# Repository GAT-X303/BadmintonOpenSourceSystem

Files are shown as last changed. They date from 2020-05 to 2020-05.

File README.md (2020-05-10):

# BOSS - Badminton Open Source System

## Introduction
Badminton can be costly to play with the ever growing cost of equipment. However, it is also important to train fundamentals through drilling. This can be hard for people who lack skilled training partners and most resort to coaching. Coaching itself can be expensive and at time it can be more productive to work on other skills instead of basic shots. BOSS aims to fix this by providing an open source badminton feeding system that will help those who cannot afford it, or those who choose not to.

Please see a detailed overview on my website
https://gat-x303.github.io/projects/BOSS/BOSS.html

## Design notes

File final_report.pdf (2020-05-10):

# BADMINTON OPEN SOURCE SYSTEM

## Final Project Report

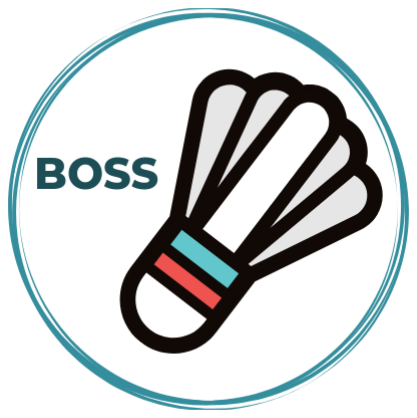
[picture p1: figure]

### APRIL 11, 2019

ENGINEERING DESIGN – ELECENG 4OI6 Nicholas Amoirm Dyllan Appelbohm Allan Hieng Mackenzie Wiens

## Table of Contents

### Acknowledgements

We would like to acknowledge Dr. Shirani for all his support, Gavin Crasto for his assistance 3D printing components, and the boys of 26 Haddon for letting us take over their living room during the build. Lastly, thank you to all women in the engineering, for without equal representation we will always fail in our duty to society.

## Final Report

### Introduction

The BOSS (Badminton Open Source System) is a badminton birdie launching system that reduces training obstacles for players of all socio-economic backgrounds. This system contains the physical launching device and a user-friendly android app that when paired together create a training environment for all! Within the app, user will have the option to select either pre-programmed launching patterns or create their own based on the type of shot, and the lateral location they wish to receive it.

Motivation
Badminton is a growing sport in Canada and is popular worldwide. A common limitation for players is the lack of consistent training scenarios. The BOSS System is an open source programmable Bluetooth device that will act as an accurate launcher. Ideally this device is an affordable option for players of all levels.

Background
In badminton training programs there are very few alternatives to private coaching. One alternative that some have tried to capitalize on are automatic feeding machines. However, these machines are not robust, difficult to purchase, and expensive. One of these machines is the patent-pending Black Knight Trainer Pro. This device has basic functionality and is not user-friendly. It requires the user to bring a laptop with a rudimentary desktop application. Furthermore, this device is not even available for purchase. The newest product is the Baddy, a badminton “robot” that you can assemble yourself or purchase ready-to-go. This device has a mobile application (although its interface is not intuitive) and does function, but it is very expensive. It cost approximately $600 CAD plus shipping (from Europe). Furthermore, this device is not open source, so any type of improvements would be very difficult to implement. Our objective was to build an open source, user-friendly, economic, automatic shuttlecock launcher. This will ultimately grow the game of badminton through providing better training opportunities to all athletes regardless of economic class.

There are six main types of badminton
shots (as seen in Figure 1), the BOSS in its
current iteration can hit three: smash (middle back of court), drop (middle of the court), net-drop (front of court) in 3 separation lateral directions (left, center, right) for a total of nine separate shots.

Project Goals & Planned Approach

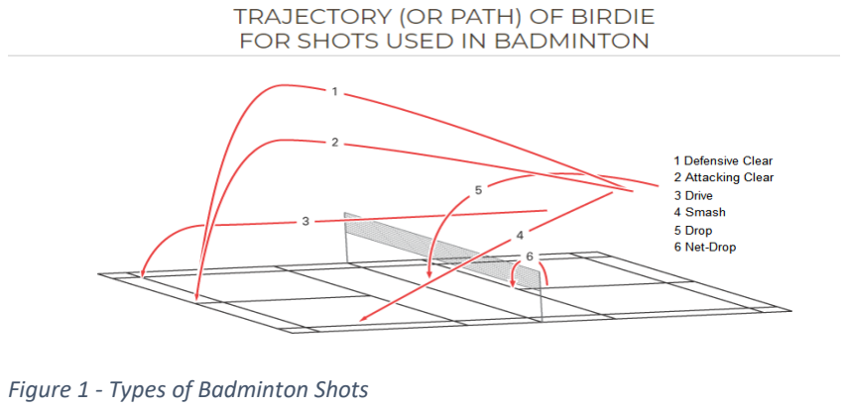
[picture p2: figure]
Figure 1 - Types of Badminton Shots

Our proposed Gold Project” had the following features:

Physical Device | Android App Capability
- Lateral movement (left, right, center)
- Linear movement (to hit back court
shots)
- Bluetooth connection
- Pre-programmed shot locations
- Ability to customize patterns for shots

- Battery Powered
- All STL files open source
- Open source app template
- Open source Arduino code The device that we created included the following features:
Physical Device | Android App Capability
- Lateral movement (left, right center)
- Piston to control back, middle, or front
shots
- Only Brushless Motors Battery Controlled
- All STL and SVG files open source
- Bluetooth connection
- Press shot location and device shoots
- Within the app: opportunity for pre-
| programmed shot locations and ability to customize patterns for shots. But not on the Arduino end.
- Open source app template
- Open source Arduino code
Milestone Descriptions | Start Date | End Date | H
M1: Build launching mechanism | October 2018 | December 2018 | 50
M2: Prototype wheels to reduce slip | October 2018 | March 2019 | 30
M3: connect Arduino to brushless and stepper motors | December 2018 | February 2019 | 40
M4: Android app development | January 2019 | March 2019 | 60
M5: Build launch tube and birdie ramp | March 2019 | March 2019 | 20
M6: Design and testing of piston | March 2019 | April 2019 | 20
M7: Assembly of physical device (laser cut gears, mounts, and housing) | March 2019 | April, 2019 | 10
M8: Integrate the physical design (launching stepper motors, direction stepper motors, and brushless motors) with Arduino | April, 2019 | April 7th, 2019 | 10
M9: Integrate android app with Arduino | April 7th, 2019 | April 8th, 2019 | 5
M10: Final testing and tweaking | April 8th, 2019 | April 8th, 2019 | 10

Table 1 - Timeline of Milestones & Hours Worked

### Approach Taken

Design

Basic Technical Approach
1. Develop and build a mechanism using two brushless motors to launch a shuttlecock by applying voltage to the motors.
2. Test different wheel materials and sizes for the best results
3. Introduce secondary stepper motors to move the original mechanism left and right (lateral movement).
4. Laser cut gears to increase torque and direction for the device when moving laterally.
5. Create the wood housing for the device.
6. Design a passive feed tube to hold birdies and use stepper motors to dispense.
7. Design sliding ramp (piston) system to alter shot distance.
8. Begin Arduino code development
a.
9. Integrate Arduino with device for controlling motor voltages.
10. Attach device to tripod; design and implement attachment.
11. Test and record ramp position based on required distance and lateral direction.
12. Android app development
a. Sketch app flow
b. Design background images
c. Create homepage
d. Create buttons that open a new activity (new page)
e. Create an array & variable to store the int that will be sent to the Arduino
f. Create Bluetooth protocol (open socket to connect with Arduino)
13. Integrate device with app
14. Integrate battery power into the device.
15. Fine tune the aim of device both longitudinally and laterally.

Design Process
The process of designing the device revolved around the goal to shoot one undamaged birdie at a time to consistent locations by controlling the vertical angle, horizontal angle, and power of the shot. Keeping simplicity in mind, a flywheel system was chosen as the best way to launch the birdies. Since the flywheels would damage the feathers significantly, the feeding system was designed to keep the feathers of the birdie upright so they wouldn’t get caught. During testing a track was implemented to easily feed the birdie into the wheels and due to pivoting flywheels pivot point was made around the center point of the birdie so that the track could remain stationary (as seen in the below figures). Lastly, two interlocking gears were used to turn the flywheels left and right so the stepper motors did not have to be powerful and to reduce the weight that would be directly resting on one motor.

At this point in the design process the ability to vary the vertical angle of the shot was abounded due to the difficulty it would take to pivot the entire machine. The BOSS was mounted at a constant angle of 12 degrees using a tripod to get the most distance out of the shots.

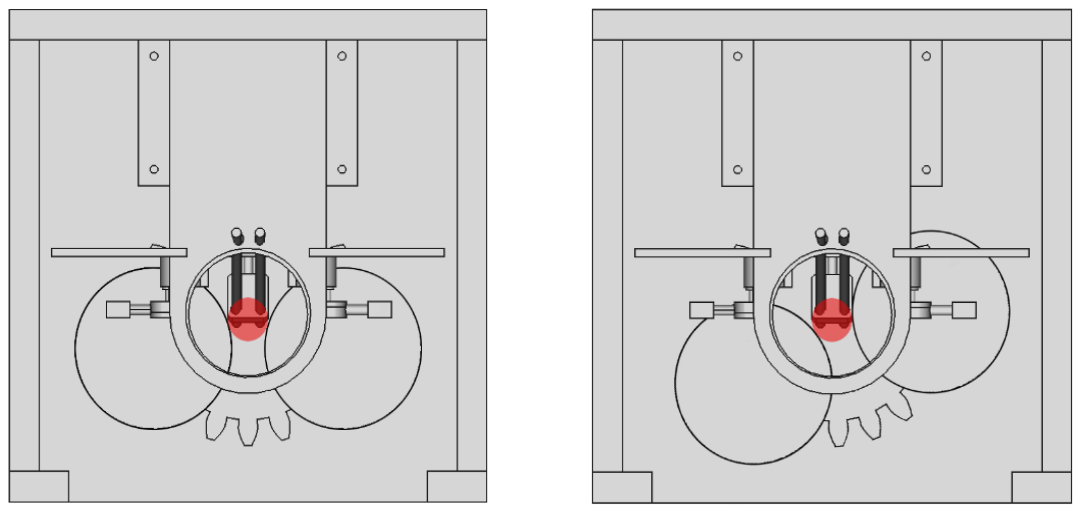
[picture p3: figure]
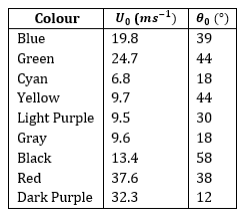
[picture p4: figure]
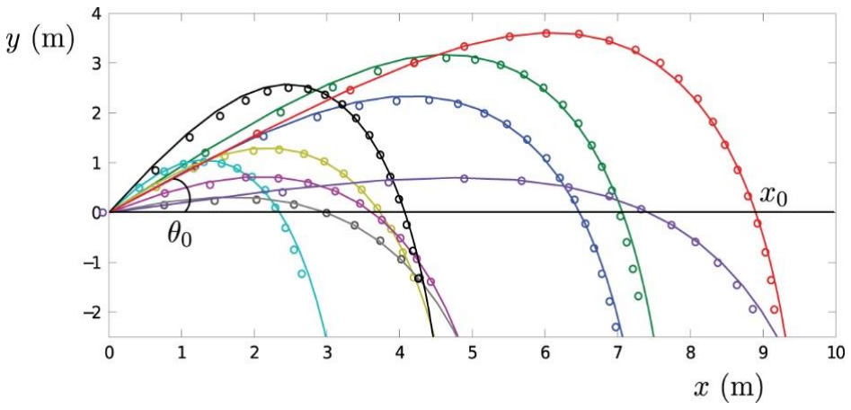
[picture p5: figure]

Figure 4 - Comparison between the observed trajectories (circles) and trajectories calculated with a pure drag equation and (solid line) for different initial conditions.

The next challenge was moving the birdie from the storage tube to the flywheels. A 3-inch mailing tube and the elastic part of a sock was used to hold back the birdies before changing the sock for a foam gasket. The supports for the tube and the dropper were designed to fit together nicely to add additional stability to the dropper arms. The arms were tipped with the same foam material
that the tube gasket was made from due to its soft and springy
properties.The last challenge was to come up with a way to vary the
distance that the birdie was shot. Varying the speed of the brushless motors did not change the distance of the shot significantly since the brushless motors were too weak to deal with the resistance of the birdie. A solution was found while manually feeding birdies through the flywheels, when the cork on the birdy didn’t line up properly with the wheels the birdie didn’t travel as far. A small piston was designed to adjust the distance between the track and the wheels
which would allow us to control how much of the cork would be
gripped by the flywheels. This allowed the BOSS to shoot net shots
as well as the farthest shots. | Table 2 - Initial Conditions for Figure 4

Figure 2 - The track remains stationary while the flywheels rotate around the center point of the

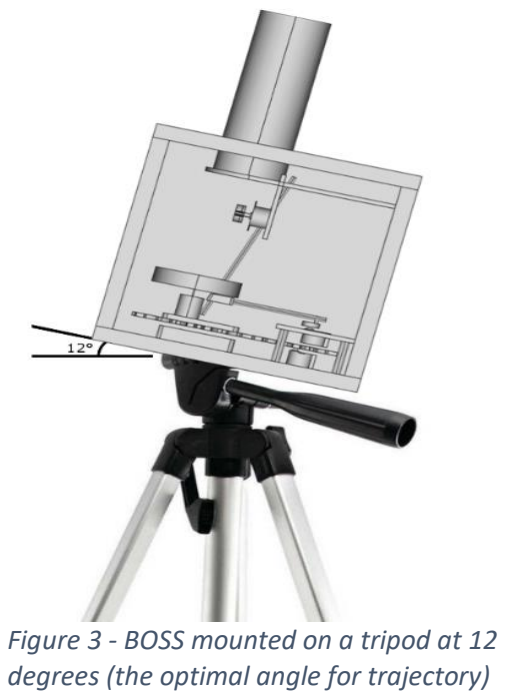
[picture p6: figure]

Figure 3 - BOSS mounted on a tripod at 12 degrees (the optimal angle for trajectory)

Modeling & Simulation
Device Drawing

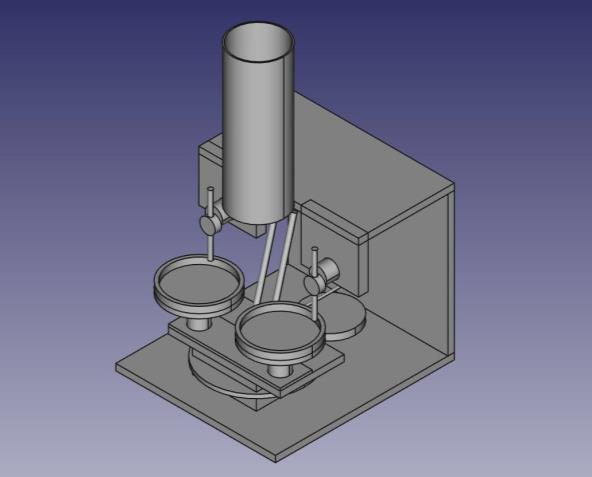
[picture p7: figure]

Laser Cut Parts
- Pulldown motor hub (2)
- Flywheels (2)
- Piston motor hub
- Feed ramp connector

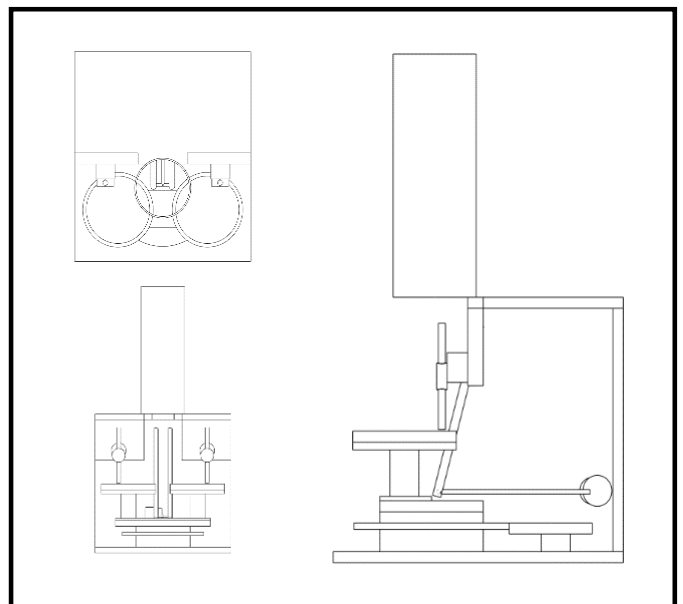
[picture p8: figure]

3D Printed Parts
- Main & Secondary gears
- Brushless motor plate
- Lazy Susan bearing spacer
- Piston motor shelf
- Tube mounting plate
- Pull down motor mounting plate

Implementation
Physical Device
The BOSS device contains five stepper motors controlled by an Arduino which is controlled via a Bluetooth connection from an Android App. Two stepper motors are used to pull one birdie at a time from the gravity tube feeder and load them onto the track. The track position (lateral direction) and launch (linear) distance is determined by two other stepper motors. One of the steppers turns a gear which controls the lateral direction and the other stepper motor is the piston mechanism. Brushless motors are moved using a servomotor connected to a The Arduino is connected to an electronic speed controller to spin two brushless motors which are connected to flywheels that launch the birdies. When the birdie slides down the track, it is launched when it contacts the rotating flywheels

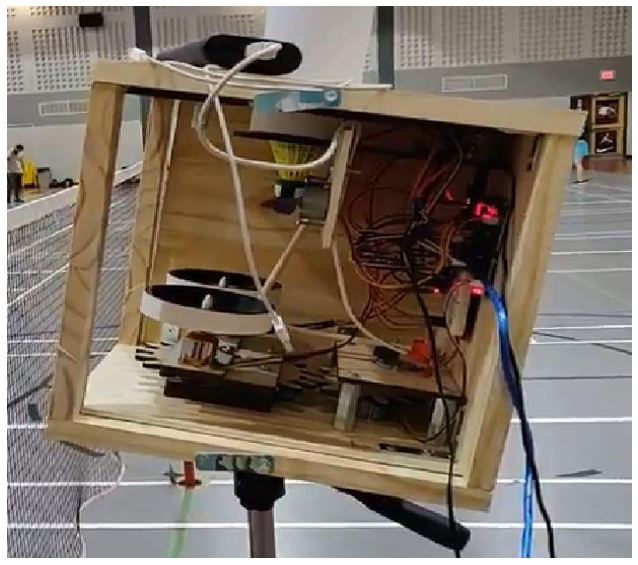
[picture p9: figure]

Figure 5 - BOSS Use Flowchart

Arduino
The Arduino is main controller of the entire device. It connects the Android app to the hardware using a Bluetooth module, the HC-06. It controls the 4 stepper motors, and the brushless motors. It provides power for the piston and bearing stepper motors. It does not provide power for the feeder stepper motors as they require more amperage to do their job. It provides the brushless motors with a square wave that is generated through pin 3, which controls the speed of the brushless motors. The AccelStepper and MultiStepper libraries were used, since they abstracted some controls of the stepper motors. These libraries were to used to control the speed and position of the various components.

The Arduino accepts Bluetooth inputs with a baud rate of 9600 since speed is not a constraint and very little data is sent at once. Once it receives data from the HC-06, a protocol designed is used to control the next actions. An integer is received, and a case statements determines the actions based on Table 5. it is ALWAYS required to press reset before powering off the device. Because it moves the device to the 0 position and all the other positions are based of this location being 0.To move each stepper motor, a function stepper.moveTo(num) was used. Where num is an integer value relative to its start position which is 0. Moving clockwise requires a positive integer, while the opposite is true for a negative number. Since the steppers used are 8 steps, the following values are used to move to key positions. Except for the feeder motors, the other motors used some values in between the key values.

The brushless motors are powered separately as they take a burst of current to run, which the Arduino cannot handle. However, the speed can be controlled by the Arduino. Since they are controlled by the duty cycle % of the PWM. Using analogWrite(pwm_pin, duty_cycle), the % duty cycle can be controlled. Anything above 60% turns the motors on. For 100% duty cycle, the value of 255 is used with 0 being 0%. 149(58%) was used for off, while 160(63%) was used was as on. These values were found by testing as the PWM of the Arduino had some noise.

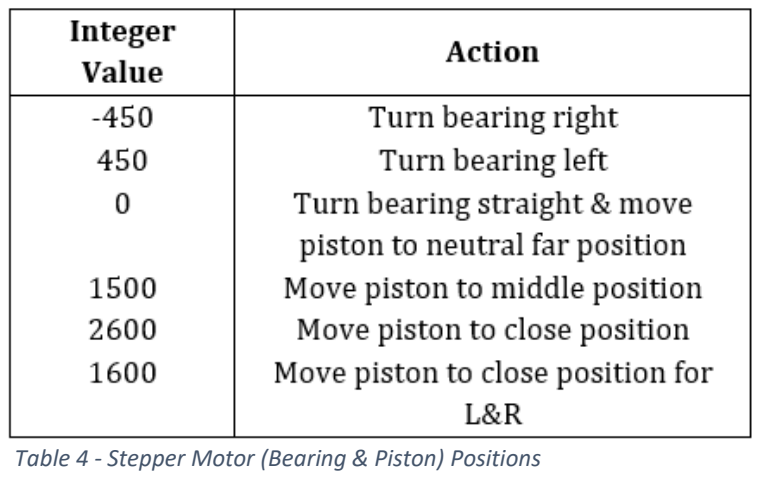
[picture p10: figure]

Table 4 - Stepper Motor (Bearing & Piston) Positions

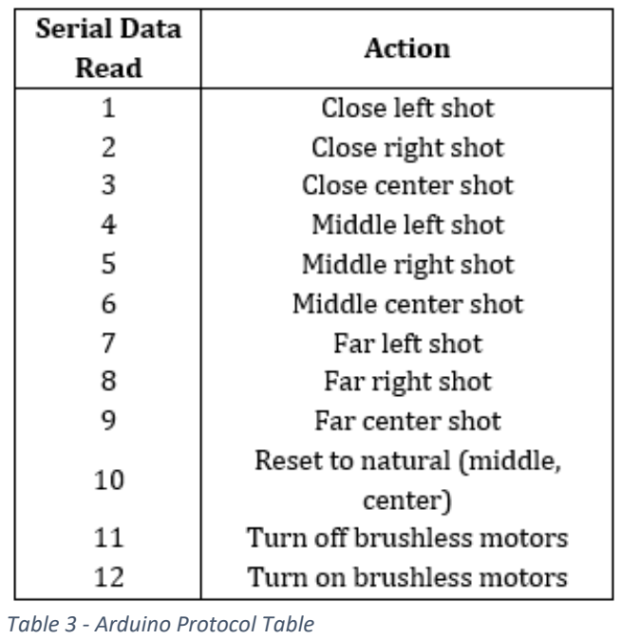
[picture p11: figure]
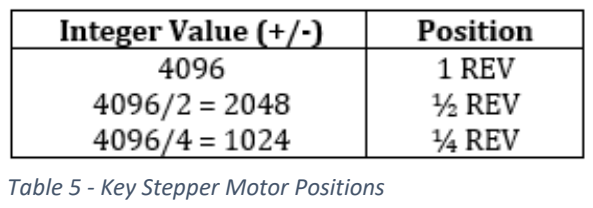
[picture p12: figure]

Table 5 - Key Stepper Motor Positions | Table 3 - Arduino Protocol Table

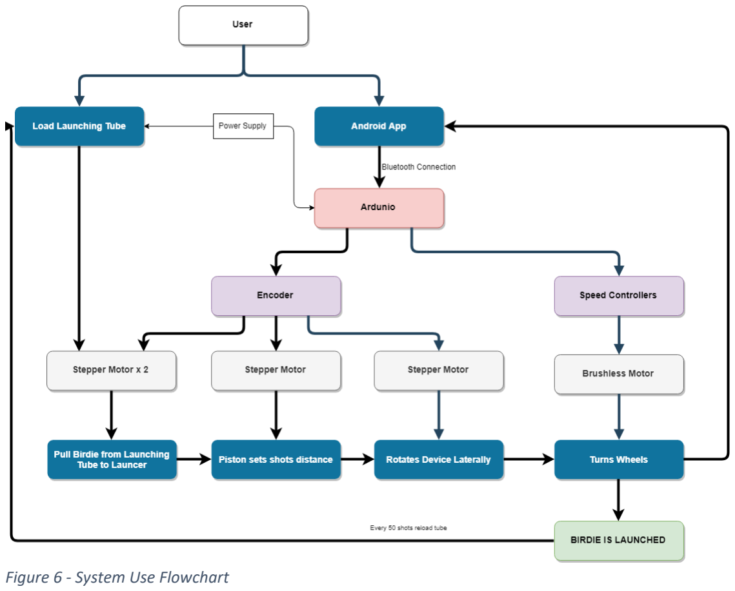
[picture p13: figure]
Figure 6 - System Use Flowchart

Android App
During the development of the physical device, a testing app was also developed. This testing app was primarily used to test the Bluetooth connection and basic functionality of the device while being the backbone of the final app. The testing app was very basic as it only featured numerous buttons to test parts of the device such as turning the bearing, adjusting the piston, and turning on and off the brushless motors. To establish connectivity, Bluetooth socket was created. Since a HC-06 was used, it can only accept connections. The socket was created with a generic UUID, which is not an issue if the device does not connect to 2 devices at once with the same UUID and the name HC-06.

This approach to the socket will continue to the final version of the app. The app in its current iteration features a homepage and the option to play three separate ways: (1) via a custom shooting pattern chosen by the user, (2) pre-chosen shooting patterns, or (3) an “immediate shot” that when the player selects the location the birdie is shot there. The app is set up for these 3 options, but the Arduino connection only interfaces with the option (3). When the user opens the app and selects “Immediate Shots”, a Bluetooth socket opens (the same type of socket that was used during testing) and the app begins to listen for a button click. The user must first press the “On” button to turn on the brushless motors and then can begin selecting locations. When a location is selected, an integer is sent to the Arduino (based on table 5).

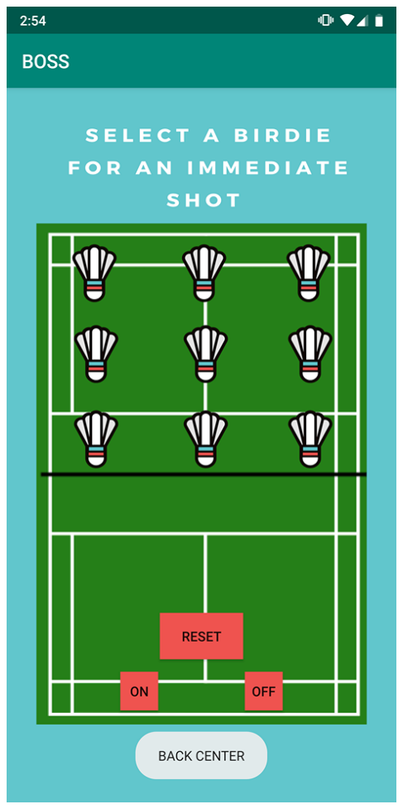
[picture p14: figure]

Figure 7 - Interactive Shooting Page; with Toast Message of which button clicked

### Critical Problems Solved

Launching Mechanism
Launching the birdie to the back of the court without damaging any of its feathers has been the largest issue we faced and where most of our solutioning has come from. To solve this problem the following steps were taken:
1. Brushless motors with flywheels were chosen as the mechanism
2. Shooting tray was utilized to limit feather contact with motors
3. Launching arms act as guides down the tray to ensure that the birdie is launched correctly and without damage.
4. Passive feeding tube with gasket was used to ensure

Changing Shot Distance
Once the we knew that the birdies could be shot, getting different distance became difficult. There was is slippage between the birdie and the wheels which makes it difficult to hit long shots.
1. Grip tape was first used to reduce slippage (but the motors spun to fast for this work around).
2. Plastigrip spray was used on the wheels to manufacture grip
3. Device was tilted at 12 degrees to get optimal results
4. Piston introduced to change distance based on birdie to wheel contact.

### Battery Power

The initial goal was to have a battery powered device to eliminate any power obstacles players may face, the below calculations were done to determine power usage.

Battery: 4800 mAℎ

Arduino: 45mA Stepper: 70mA × 4 = 280mA HC06: 8mA Brusℎless Motors: 1A − 20A

Device Operates at ~1A,tℎerefore Total Amperage = 1333mA

4800mAℎ
1333mA = 3.6 H

The battery should have lasted for more than 3H but based the battery could not handle the ‘bust’ of power needed to turn the motors as it exceeds 2A (as seen in the Figure 8). To solve this power usage, the Arduino was battery operated but 2 separate “plug in” power sources were used to power the device.

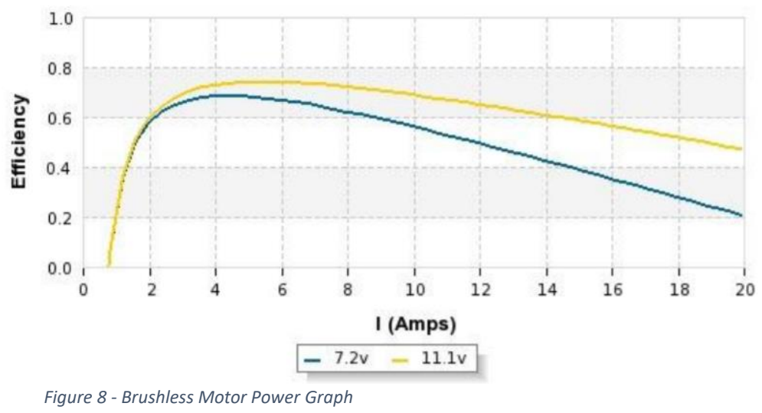
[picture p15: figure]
Figure 8 - Brushless Motor Power Graph

### Conclusion

Deliverables
1. Physical Badminton Birdie Shooting Device
2. Open Source SVG and STL Files¹
3. Open Source Arduino Code²
4. Open Source Android Studios App Template³

Next Steps
Custom Grip
The plastigrip worked a mild solution to the grip problem, but there is still slippage which does not allow the flywheels to get a strong enough grip to launch the birdies to the back of the court. Increasing the voltage of the brushless motors does not correlate to a more powerful shot due to this slippage and to the resistance that the birdie provides to the wheel. The development of a custom circular “stretchy” grip to the wheels would be a next step. If full contact can be without slip, then the birdies can readh the back of the court. Once this issue is resolved, we can have better app to court accuracy. The shots left and right can go further, and the Arduino power settings can be change for an all around more accurate experience.

App & Android Integration
Currently the Arduino only reads in an integer and then launches a birdie. Moving forward, there would be further integration so that the app reads loops through a custom or pre-defined shooting pattern and sends those integers to the Arduino.

App Development
The app has basic functionality with a basic interface that is only set up for a 2XL Pixel smart phone. Moving forward, it would be developed using more relative constraints with relative images (not prefixed size images with fixed constraints). Furthermore, an iOS app would also be developed so iPhone user can also use this device.

Physical Housing
The laser cut logo and pine would looks nice, but we would add a darker finish to the wood and organize the inside of the box. Currently the wires are optimally organized, and it is difficult to reach the Arduino to manually reset it. We would organize the inside of the box and add a compartment for the battery.

### Future

As discussed in the background, there are currently two similar devices on the market, the Black Knight, which is still unavailable for order and the Baddy, an expensive European option. The Baddy is a $600 CND device, our final device cost is $175, and we believe that with some fine tuning we can easily get that cost down to $120. Our system also has a much more intuitive app and is in located Canada. For North American and European badminton players, our device is already more accessible. There are millions of badminton players worldwide and even in Canada, where badminton is not seen as a “popular” sport, almost every city has a badminton club with players who want to train but lack access to consistent training partners. Even at McMaster, the gym is filled daily with badminton players. This device can be used for competitive players

1
Search “Badminton Open Source System Parts” on Thingiverse
2
Search “Badminton Open Source System” on Github located with Android App Code
3
Search “Badminton Open Source System” on Github for both java and XML code, located with Arduino Code looking to get an edge on their competition (or even just have access to quality shots) and for those just a fun and easy way to exercise.

Open Source Kits for Purchase
Our device can be marketed to players of all socioeconomic background. We are currently looking at having three separate price options. For players willing to pay the most, the BOSS can be sent assembled and ready to be used. We think a popular option will also be the BOSS Kit. A ready-to-assemble kit with pre-cut parts, all the motors, and hardware. Lastly, for those looking to keep costs down, we can have a “just the essentials”, the player would have to download the SVG and STL files themselves and can choose which hardware pieces they need. If a player already had an Arduino, brushless motors, and wires, they would be able to order a customizable kit that contained the stepper motors and hardware needed.

What’s Next

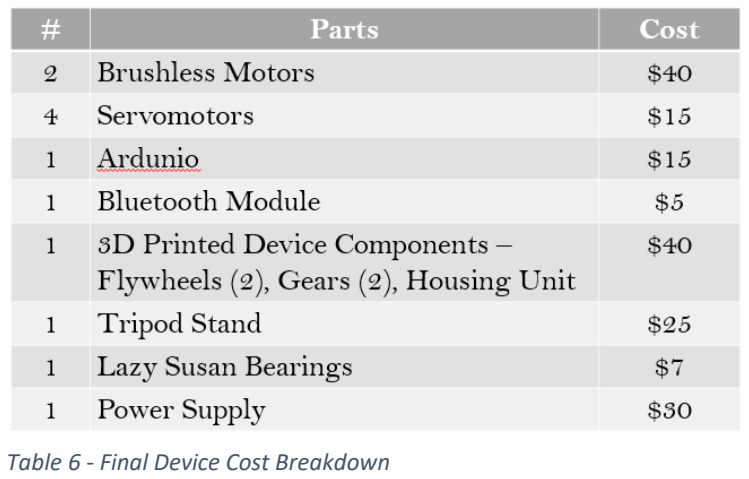
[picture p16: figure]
Table 6 - Final Device Cost Breakdown

Our project is a holistic showcase of five years of engineering education, from first year CAD drawing and second year java and Arduino coding all the way to fourth year socket knowledge. We look forward to making continuous improvements to the physical device, Arduino code, and android app and hope to move from the prototype to market device. We are looking forward to investing the prize money back into the device and looking into entrepreneurial competitions to win more funds to further improve the BOSS.

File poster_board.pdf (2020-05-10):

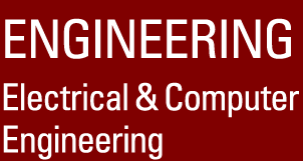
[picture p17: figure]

# Badminton Open Source System

# BOSS

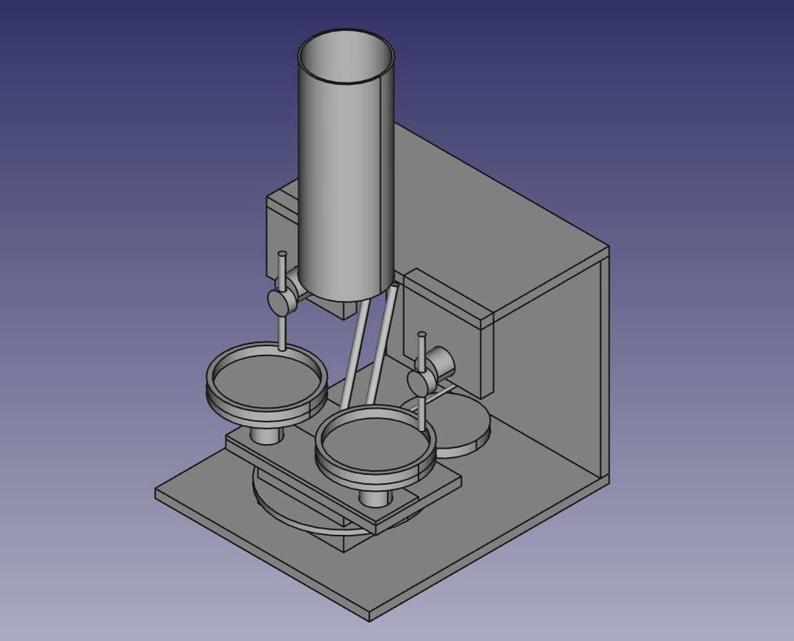
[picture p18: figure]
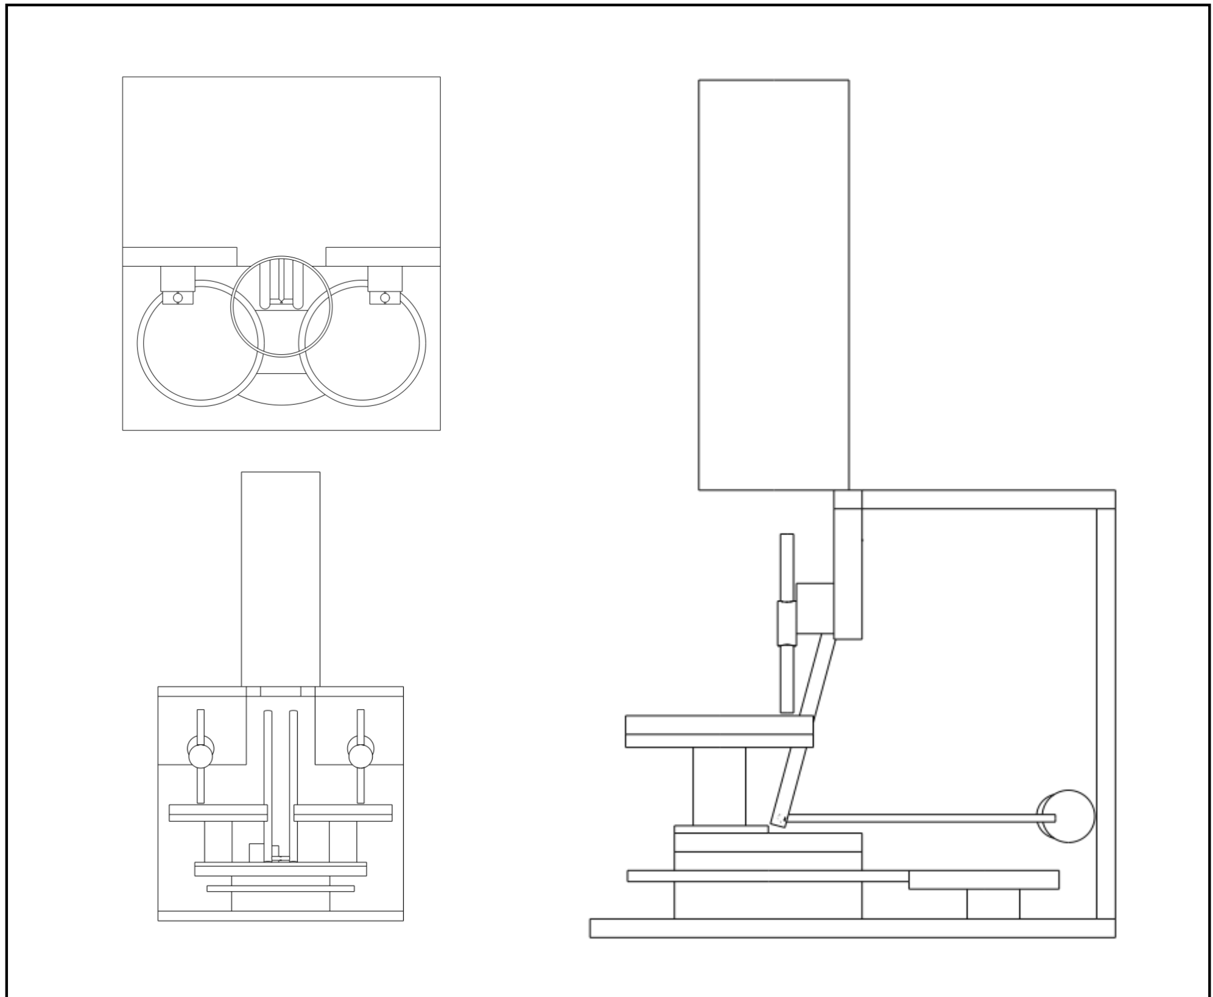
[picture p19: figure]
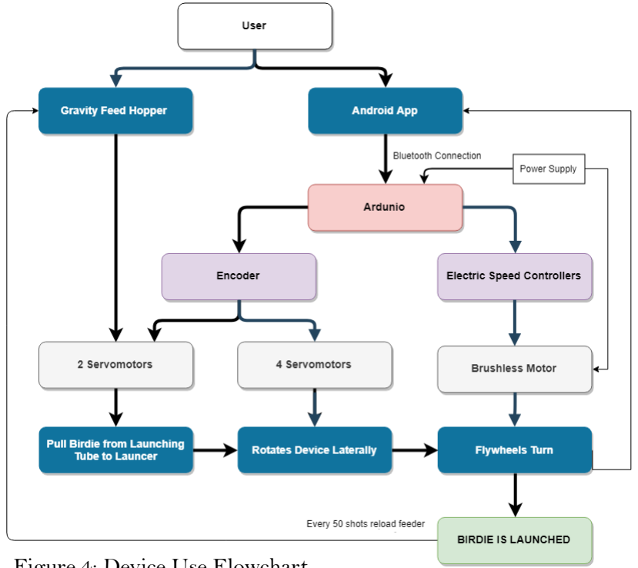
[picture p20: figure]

### Engineering Design – ELECENG 4OI6

### Group S01

Nicholas Amorim | Dyllan Appelbohm | Allan Hieng | Mackenzie Wiens

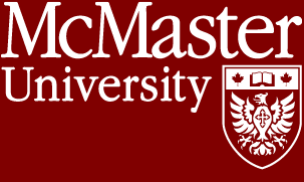
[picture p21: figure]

# Motivation

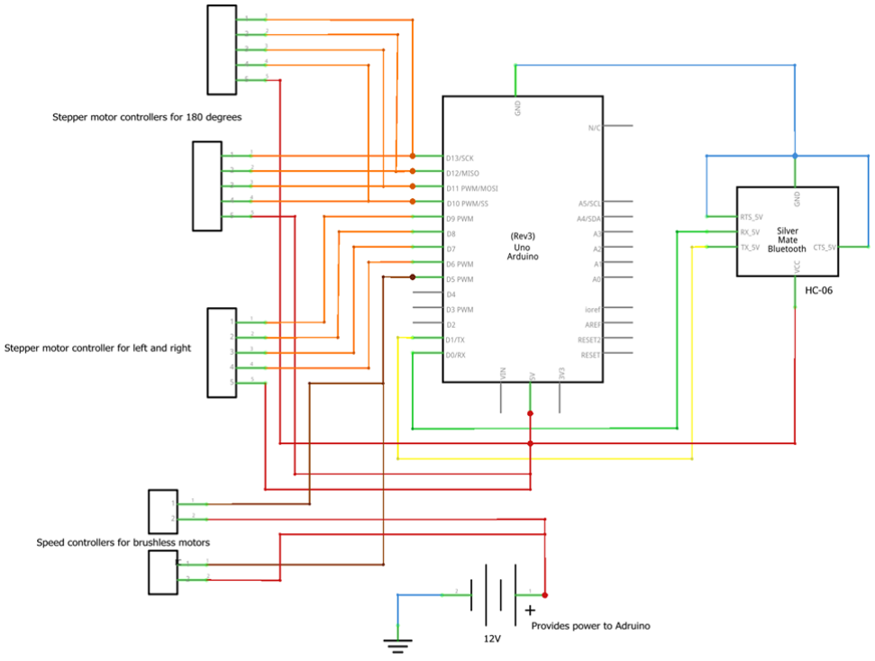
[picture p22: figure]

# Final Device

# Microcontroller

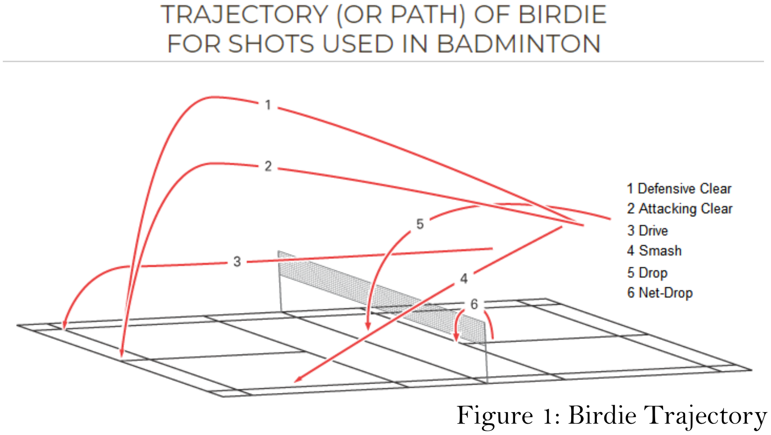
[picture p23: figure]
Figure 1: Birdie Trajectory

# Timeline Mechanical Design Process

# Technical Drawings

# Project Description

The BOSS (Badminton Open Source System) is a badminton birdie launching system that reduces training obstacles for players of all socio-economic backgrounds. This system contains the physical launching device and a user-friendly android app that when paired together create a training environment for all! Within the app, user will have the option to select either pre-programmed launching patterns or create their own based on the type of shot, and the lateral location they wish to receive it.

Badminton is a growing sport in Canada and is popular worldwide. A common limitation for players is the lack of consistent training scenarios. The BOSS is an open source programmable Arduino device that will act as an accurate launcher for all!

There are six main types of badminton shots. The BOSS can currently shoot three (#4-6) types: smash, drop, and net-drop, in three different lateral positions: left, center, right. User can choose their difficultly by choosing patterns that exploit the wide left and right regions of the court or by decreasing timing between shots.

Milestone Descriptions | Start Date | End Date | H
M1: Build launching mechanism | October 2018 | December 2018 | 50
M2: Prototype wheels to reduce slip | October 2018 | March 2019 | 10
M3: connect Arduino to brushless and stepper motors | December 2018 | February 2019 | 40
M4: Android app development with Bluetooth capabilities | January 2019 | April 2019 | 40
M5: Build launch tube and birdie ramp | March 2019 | March 2019 | 15
M6: Assemble all components and build final design | March 2019 | April 2019 | 30
# | Parts | Cost

2 | Brushless Motors | $40
4 | Servomotors | $15
1 | Ardunio | $15
1 | Bluetooth Module | $5
1 | 3D Printed Device Components – Flywheels (2), Gears (2), Housing Unit | $40
1 | Tripod Stand | $25
1 | Lazy Susan Bearings | $7
1 | Power Supply | $30
Deliverables
- Bluetooth enabled launching device
- Open Source Device SLT Files
- Open Source Arduino Code
- Android Studio Public App Template

The BOSS device is loaded and steered by four servomotors controlled by an Arduino (which is controlled via a Bluetooth connection from the Android App). The BOSS device then uses the Arduino that is connected to an electronic speed controller to spin two brushless motors which are connected to flywheels to launch the birdies. Two additional servomotors are used to pull one birdie at a time from the gravity fed hopper and load them onto the track. The track position and launch distance is determined by a servomotor controlled piston mechanism. The two brushless motors are steered using a servomotor connected to a gear train under the brushless motors to rotate the device depending on the shot direction. When the birdie slides down the track, it is launched when it makes contact with the rotating flywheels

The Arduino is the control unit of the entire device. It is controlled via Bluetooth (HC-06 module) with an App. When it receives data of from the App, which was built in Android Studio, our basic protocol is designed to decide its next actions. It communicates with the stepper motors through an encoder and the stepper.h library. This allows it to position anywhere from 0° to 360° based on its relative position. It communicates with the brushless motors through the electronic speed controller. The speed controller accepts PWM of varying duty cycles, which is why the given pin is chosen. The speed of the motors is controlled by duty cycle so higher duty cycles result in a higher speed. Lastly, everything is powered by battery capable of 12V because this the required voltage for the brushless motors.

Badminton Knowledge

Figure 4: Device Use Flowchart

Figure 3: Engineering Drawing

Figure 5: Arduino Technical Drawing

Figure 2: Isometric View

We would like to acknowledge Dr. Shirani for all his support, Gavin Crasto for his assistance 3D printing components, and all women in the engineering, for without equal representation we will always fail in our duty to society.

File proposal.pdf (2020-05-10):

## NICK AMORIM || DYLLAN APPELBOHM

## ALLAN HIENG || MACKENZIE WIENS

# Executive Summary

# - The BOSS stands for Badminton Open Source Software System - Badminton birdie launching system that reduces training obstacles for players of all socio-economic backgrounds ▪The system contains a physical launching device plus an android app that selects the launching patterns

# Motivation

“Badminton is a growing sport in Canada and is popular worldwide.

## A common limitation for players is the lack of consistent training scenarios. The BOSS System is an open source programmable Bluetooth device that will act as an accurate launcher. Ideally this device is an affordable option for players of all levels.”

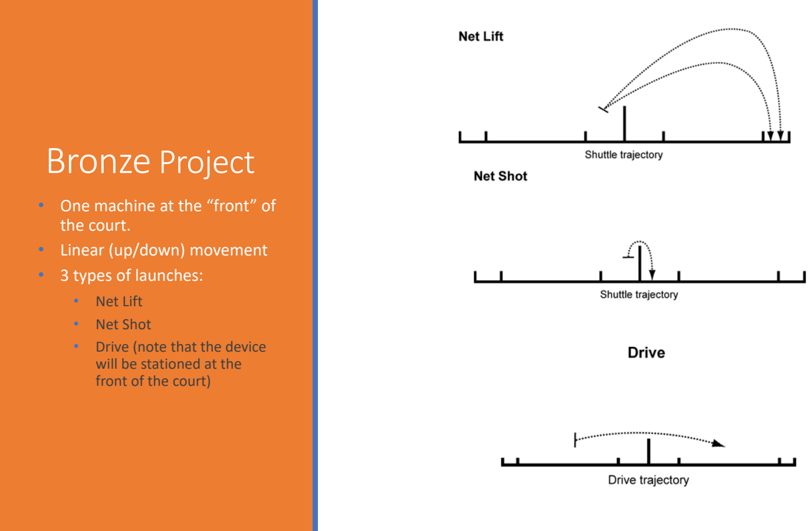
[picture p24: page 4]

# Bronze Project

- One machine at the “front” of the court.
- Linear (up/down) movement
- 3 types of launches:
- Net Lift
- Net Shot
- Drive (note that the device will be stationed at the
front of the court)

- Silver Project
- Add shots 3-4 from the
diagram. Similar trajectories as bronze project, but
additional option to have
shots come from the back
of the court.
- Add lateral movement
(left/right) for all 6 shot types.


- Gold Project
- Add shots 1 & 2, defensive & attacking clears with
lateral options.
- Battery powered
- Build a second device for a multi-launcher system.

# Background


BLACK KNIGHT TRAINER PRO | BADDY

# Technical Approach

1. Building Shooting Tray
2. Linear Movement (first 3 shots)
3. Housing Device
4. Incorporate microcontroller
5. App development
6. Back of Court Shoots
7. Lateral Movements
8. Testing
9. Battery Powered
10. Build second device

# Resources

- Microcontroller interfacing
- Digital Signal Processing
- Android Application development (Java)
- Knowledge of badminton game mechanics
- 3D printing modelling
- Prototyping (assembly)

# Components & Funds

Quantity | Parts (1 Device) | Approx. Cost (S)
2 | Brushless Motors | $65
1 | Plastic Housing | $50
1 | Stand Material (Tripod) | $50
1 | Microcontroller | $10
1 | Plastic Tube | $25
1 | Bluetooth Module | $10
1 | AC Power Adapter | $40
1 | Battery | $60

# Schedule & Milestones

Description | Date (Completed By) | Approx. Time Needed (H)
1: Launching mechanism with linear movement & physical housing | Mid-November | 5
2: Record voltages needed to achieve Bronze Project launches | December | 10
3: Record voltages needed to achieve back shots | Mid-January | 5
4: Connect microcontroller to device | January | 2
5: Create app | Mid-March | 100
6: Add lateral movement and record voltages/angles/timing | Mid-January | 10
7: Create additional device & sync with app | February | 50
8: Additional testing with launch variances | March | 40

# Risks & Alternative Plan

- Flywheels as launching source
- Fast spinning wheels could damage the birdie.
- Alternative: use slingshot style system.
- Bluetooth range limitations
- Range = 32 ft, which is 8 ft shorter than full Badminton court.
- Alternative: use wi-fi system or look at more expensive Bluetooth devices.
- Motor Power
- Not enough power to launch birdie’s from back of the court.
- Alternative: purchase a more powerful motor/microcontroller.

# Deliverables

## 1. Bluetooth, Battery powered Badminton Birdie Launching Machine 2. Android App 3. Open Source Microcontroller (Arduino) Code

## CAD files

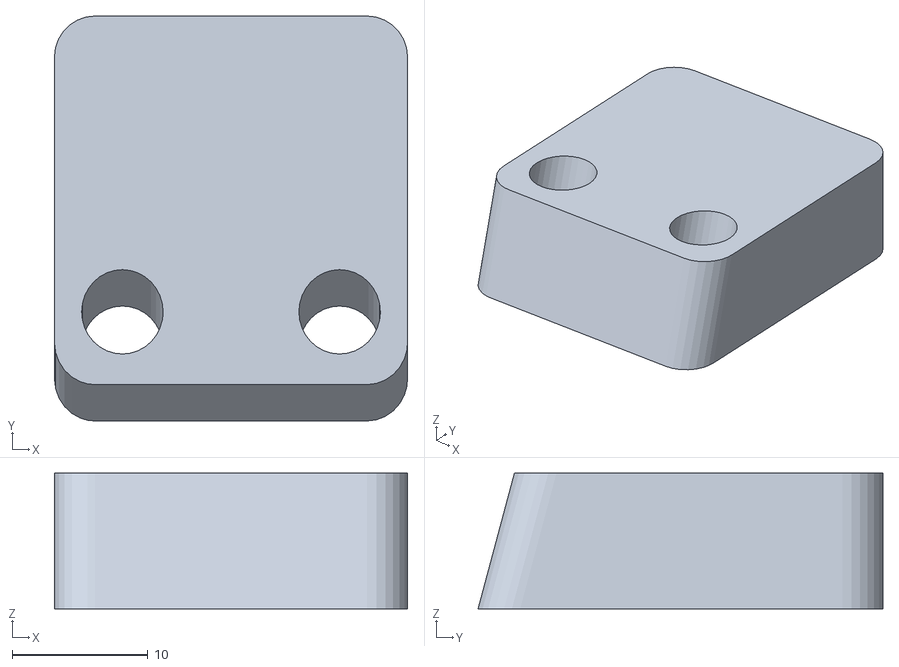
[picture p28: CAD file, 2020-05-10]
STLS/Piston_End.stl
26.0 x 29.8 x 10.0

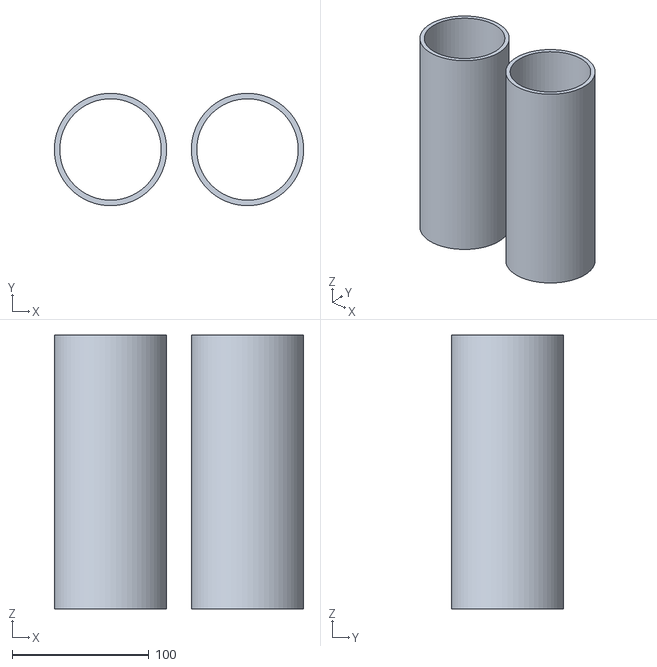
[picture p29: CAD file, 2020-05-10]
STLS/Tube_2Parts.stl
182.0 x 82.0 x 200.0

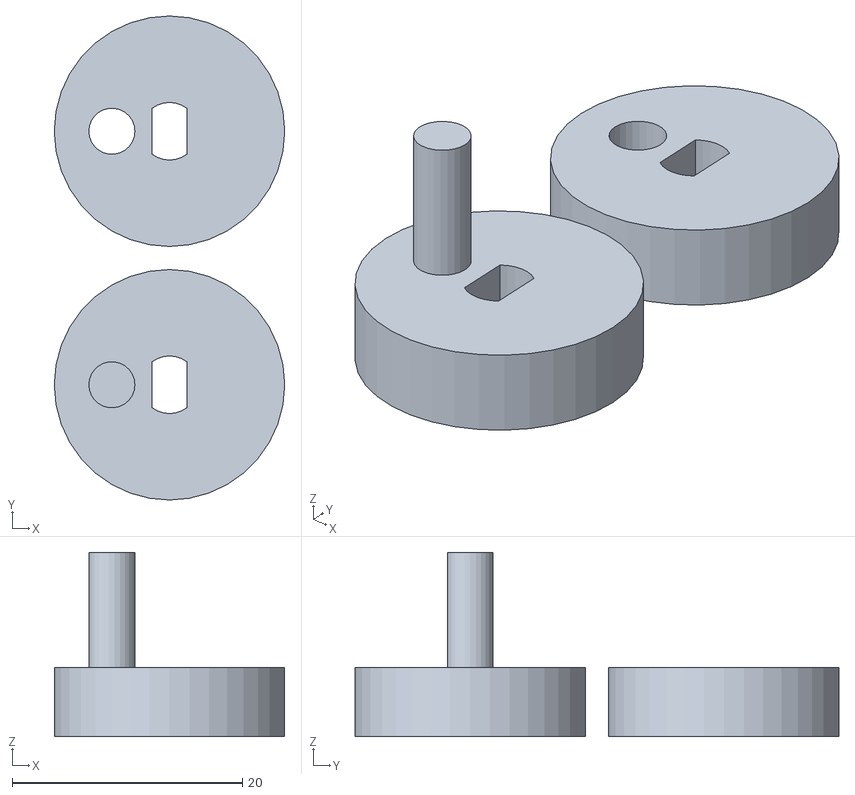
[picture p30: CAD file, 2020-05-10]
STLS/Piston_Mount.stl
20.0 x 42.0 x 16.0

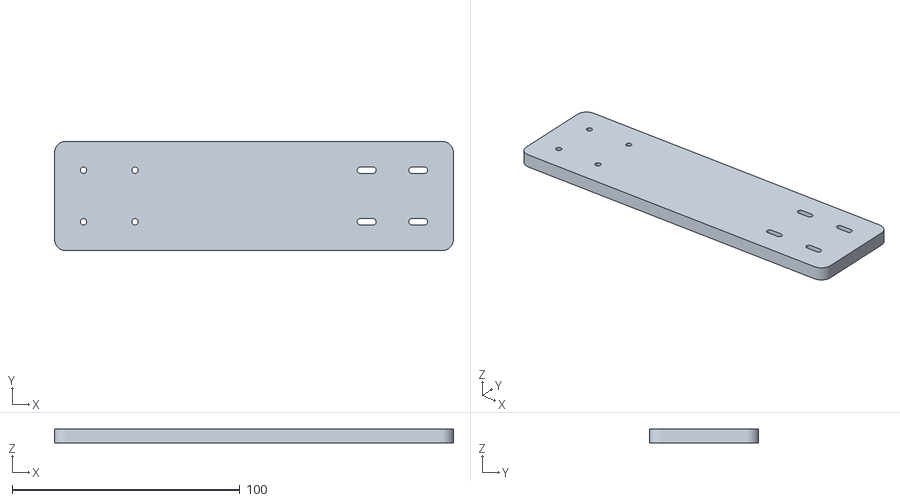
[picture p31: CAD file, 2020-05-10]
STLS/Capstone_Base.stl
175.0 x 48.0 x 6.35

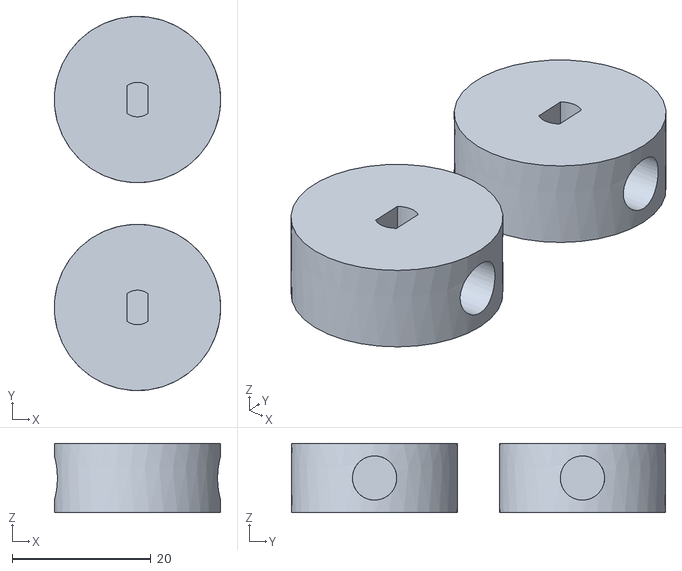
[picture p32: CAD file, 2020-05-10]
STLS/Arm_Mount.stl
24.0 x 54.0 x 10.0

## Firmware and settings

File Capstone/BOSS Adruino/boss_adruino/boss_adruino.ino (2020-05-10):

//https://cyaninfinite.com/moving-the-28byj-48-stepper-motor/s

#include <AccelStepper.h>
#include <MultiStepper.h>

#define HALFSTEP 8  //Half-step mode (8 step control signal sequence)

//Motor pin definitions
#define bearing_mtrPin1  13
#define bearing_mtrPin2  12
#define bearing_mtrPin3  11
#define bearing_mtrPin4  10

#define feeder_mtrPin1 9
#define feeder_mtrPin2 8
#define feeder_mtrPin3 7
#define feeder_mtrPin4 6

#define pwm_pin 3

#define piston_mtrPin1 A0
#define piston_mtrPin2 A1
#define piston_mtrPin3 A2
#define piston_mtrPin4 A3
//


//some stepper motor areas
#define clockswise_fullCricle 4096
#define counter_fullCircle -4096
#define left 
//

#define brushlessOff 149
#define brushlessOn 160


int feederPos = 0;
int serial_input = 0;

AccelStepper bearing_stepper(HALFSTEP, bearing_mtrPin1, bearing_mtrPin3, bearing_mtrPin2, bearing_mtrPin4);
AccelStepper feeder_stepper(HALFSTEP, feeder_mtrPin1, feeder_mtrPin3, feeder_mtrPin2, feeder_mtrPin4);
AccelStepper piston_stepper(HALFSTEP, piston_mtrPin1, piston_mtrPin3, piston_mtrPin2, piston_mtrPin4);

void setup() {

  Serial.begin(9600);

  //sets the PWM to 50% b/c the motors need starting value >0% but <63%
  pinMode(pwm_pin, OUTPUT);
  analogWrite(pwm_pin, brushlessOff);

  //set parameters to the stepper motors
  bearing_stepper.setMaxSpeed(2000.0);
  bearing_stepper.setAcceleration(200.0);
  bearing_stepper.setSpeed(1500);

  feeder_stepper.setMaxSpeed(3000.0);
  feeder_stepper.setAcceleration(300.0);
  feeder_stepper.setSpeed(1500);

  piston_stepper.setMaxSpeed(2000.0);
  piston_stepper.setAcceleration(200.0);
  piston_stepper.setSpeed(1500);
  //
}

void loop() {

  //start the stepper motors
  feeder_stepper.run();
  bearing_stepper.run();
  piston_stepper.run();
  
  if (Serial.available() > 0){

    serial_input = Serial.read();
    
    Serial.println(serial_input);

    //close left shot
    if (serial_input == 1){
      pistonPosCloseLeftRight();
      turnLeft();
      feedBird(feederPos);
    }

    //close middle shot
    if (serial_input == 2){
      pistonPosCloseMiddle();
      turnCenter();
      feedBird(feederPos);
    }

    //close right shot
    if (serial_input == 3){
      pistonPosCloseLeftRight();
      turnRight();
      feedBird(feederPos);
    }

    //left middle shot
    if (serial_input == 4){
      pistonPosMed();
      turnLeft();
      feedBird(feederPos);
    }

    //center middle shot
    if (serial_input == 5){
      pistonPosMed();
      turnCenter();
      feedBird(feederPos);
    }

    //right middle shot
    if (serial_input == 6){
      pistonPosMed();
      turnRight();
      feedBird(feederPos);
    }

    //left far shot
    if (serial_input == 7){
      pistonPosFar();
      turnLeft();
      feedBird(feederPos);
    }

    //center far shot
    if (serial_input == 8){
      pistonPosFar();
      turnCenter();
      feedBird(feederPos);
    }

    //right far shot
    if (serial_input == 9){
      pistonPosFar();
      turnRight();
      feedBird(feederPos);
    }

    if (serial_input == 10){
      pistonPosFar();
      turnCenter();
    }

    //turns off the motor
    if (serial_input == 11){
      analogWrite(pwm_pin, brushlessOff);
    }

    //turns on the motor
    if (serial_input == 12){
      analogWrite(pwm_pin, brushlessOn);
    }

  }
    
}

//close
void pistonPosFar(){
  piston_stepper.moveTo(0);
}

void pistonPosMed(){
  piston_stepper.moveTo(1500);
}

void pistonPosCloseLeftRight(){
  piston_stepper.moveTo(1600);
}

void pistonPosCloseMiddle(){
  piston_stepper.moveTo(2600);
}


void feedBird(int Pos){
  int currentPos = feeder_stepper.currentPosition();
  feeder_stepper.moveTo(currentPos - 4096);
}

void turnRight(){
  bearing_stepper.moveTo(-450);
}

void turnCenter(){
  int current_pos = bearing_stepper.currentPosition();
  if (current_pos > 0){
    bearing_stepper.moveTo(-0);
  }
  if(current_pos < 0){
    bearing_stepper.moveTo(0);
  }
}

void turnLeft(){
  bearing_stepper.moveTo(450);
}

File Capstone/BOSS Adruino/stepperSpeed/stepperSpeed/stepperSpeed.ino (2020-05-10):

#include <AccelStepper.h>
#include <MultiStepper.h>

#define HALFSTEP 8  //Half-step mode (8 step control signal sequence)

// Motor pin definitions
#define mtrPin1  8     // IN1 on the ULN2003 driver 1
#define mtrPin2  9     // IN2 on the ULN2003 driver 1
#define mtrPin3  10     // IN3 on the ULN2003 driver 1
#define mtrPin4  11     // IN4 on the ULN2003 driver 1

AccelStepper stepper1(HALFSTEP, mtrPin1, mtrPin3, mtrPin2, mtrPin4);

void setup() {
  stepper1.setMaxSpeed(1500.0);
  stepper1.setAcceleration(200.0);  //Make the acc quick
  stepper1.setSpeed(1000);
  stepper1.moveTo(4096/4);  //Rotate 1 revolution
}

void loop() {

  //Change direction when the stepper reaches the target position
  if (stepper1.distanceToGo() == 0) {
    stepper1.moveTo(-stepper1.currentPosition());  //Reverse motor
  }
  stepper1.run();  //Start
}

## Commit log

2020-05-10 Inital File Commit
    - must be sorted and filtered
    [Arm_Mount.stl, CapstoneBase.stl, Piston_End.stl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]
2020-05-11 Filtered and organized files
    [Arm_Mount.stl, Capstone_Base.stl, Piston_End.stl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]
